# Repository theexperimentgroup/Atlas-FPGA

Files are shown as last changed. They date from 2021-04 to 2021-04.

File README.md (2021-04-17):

# PROYECTO ATLAS

La placa ATLAS se diseña con el objetivo de crear un multicore basado en SBC (SINGLE BOARD COMPUTER).

Inicialmente la placa adaptadora ATLAS es un proyecto para la placa CYC1000 y la SBC Raspberry Pi.

Mas info y fotos en este [hilo](http://www.forofpga.es/viewtopic.php?f=28&t=376&p=1548#p1548), en su propio [foro](http://www.forofpga.es/viewforum.php?f=240&sid=bd3e070f65599ff111ad0494e4459535) de foroFPGA, en [telegram](https://t.me/CYC1000) o [discord](https://discord.gg/YDdmtwh).

Licensed under Cern OHL
http://ohwr.org/cernohl

### Guía rápida

Si ya tienes tu CYC1000, una raspberry Pi, y la placa ATLAS (la puedes conseguir en el grupo de [telegram](https://t.me/CYC1000)), sigue esta guía rápida para empezar a trastear. 

El proyecto está empezando y se irán simplificando los pasos en el futuro de forma que para cargar los cores ya no será necesario acceder al terminal de Linux de la placa SBC.

#### Ensamblaje de las placas:

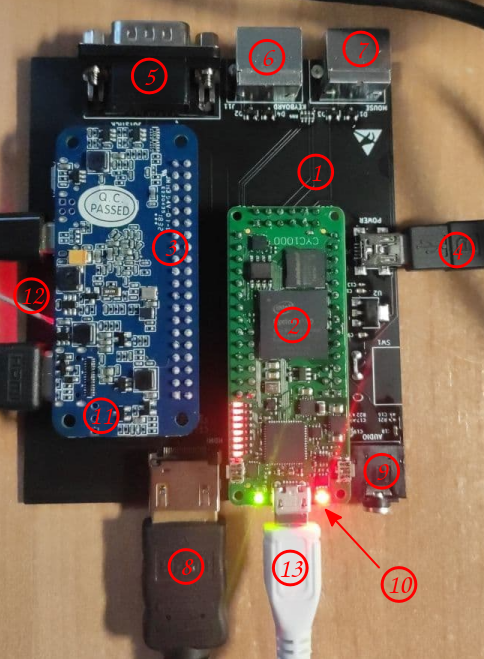
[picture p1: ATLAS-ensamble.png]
ensamblaje


Leyenda: (1) Placa Atlas, (2) FPGA CYC1000, (3) SBC Raspberry Pi, (4) Alimentación general, (5) DB9 para joystick, (6) teclado PS2, (7) ratón PS2, (8) salida video HDMI, (9) jack 3.5 audio, (10) tarjeta microSD ATLAS, (11) tarjeta microSD rPi

Otras conexiones opcionales: 

(12) Conexiones de vídeo y teclado a la SBC rPi para acceder al terminal de linux . No es necesario si has configurado acceso ssh por WiFi.

(13) USB Blaster para cargar cores directamente a la CYC1000. No es necesario si la carga se hace a través de la SBC rPi.

#### Configuración inicial de la SBC raspberry Pi

* Descarga raspberry Pi OS Lite https://www.raspberrypi.org/software/operating-systems/ y grábalo en una tarjeta micro SD
* Arranca  la SBC con la tarjeta micro SD del paso anterior en el zócalo (11) (no es necesario tenerla conectada aún a la placa ATLAS) con el video y teclado conectados y con un cargador de adecuado amperaje (>2A). 
  * Para acceder al terminal Linux de la rPI el usuario / contraseña por defecto son: pi / raspberry
* Configuración de la raspberry Pi con el comando `sudo raspi-config` (la configuración del WiFi es opcional y puedes encontrar mas información [aquí](https://www.raspberrypi.org/documentation/configuration/wireless/wireless-cli.md)): 
  * 5 Localization Options
    * L4 WLAN country 
    * L3 keyboard
  * 1 system options
    * S1 wireless LAN

#### Instalación del cargador de cores programRBF en la FPGA 

Nota: vamos a trabajar desde el directorio /home/pi que es el que aparece por defecto al arrancar el terminal Linux con el usuario "pi".

* Instala la librería WiringPi:

  ```
  wget https://project-downloads.drogon.net/wiringpi-latest.deb
  sudo dpkg -i wiringpi-latest.deb
  ```

* Compila el ejecutable para cargar los cores:

  ```
  wget https://raw.githubusercontent.com/shaeon/programrbf/main/programrbf_v01.cpp
  g++ programrbf_v01.cpp -lwiringPi -o programrbf
  ```

#### Arranca los cores desde el terminal Linux de la SBC

* Copia los cores con extensión .rbf a la tarjeta SD, en la partición "rootfs", directorio ""/home/pi".

* Carga el core con el ejecutable programrbf (el ejemplo carga el [msx_multicore2.rbf](./cores/msx_multicore2.rbf) de MSX1):

  ```
  ./programrbf msx_multicore2.rbf 17 22 4 27
  ```
  
  Nota: El core [msx_multicore2.rbf](./cores/msx_multicore2.rbf) de MSX1 requiere soldar un reloj adicional de 50 MHz, y tener una tarjeta micro SD con [este contenido](https://mega.nz/file/20pi1aiY#FwhOZryEUyuyU1gEUCVma1ndn-2BqtvH7RUx-qwgqs0) insertada en el zócalo micro SD (10) de la placa ATLAS.

#### Script para cargar un core automáticamente al arrancar la SBC

* Ejecuta los siguientes comandos en el terminal de Línux:

  ```sh
  crontab -e
  #selecciona por ejemplo nano y al final del fichero cron añade lo siguiente:
  @reboot ~/programrbf msx_multicore2.rbf 17 22 4 27
  ```

### **Reloj adicional de 50 Mhz:**

La placa CYC1000 dispone de un reloj de 12 Mhz. Algunos cores necesitan de un reloj adicional de 50 MHz a soldar en el espacio que se ve en la siguiente [foto](http://www.forofpga.es/viewtopic.php?f=240&t=390).

Dónde conseguir el reloj:

* [Arrow](https://www.arrow.com/en/products/ecs-2520mv-500-bn-tr/ecs-international?q=ECS-2520MV-500-BN-TR)

Listado de cores que van a 50 MHz:

* MSX1

### **Colaboraciones:**

Se necesita la [colaboración](https://github.com/SoCFPGA-learning/General/tree/main/Github_ayuda) para poder incrementar los recursos disponibles para la comunidad entorno esta placa de desarrollo.    

### Comunidad:

* [Telegram group](https://t.me/CYC1000) 
* [Discord channel](https://discord.gg/YDdmtwh)

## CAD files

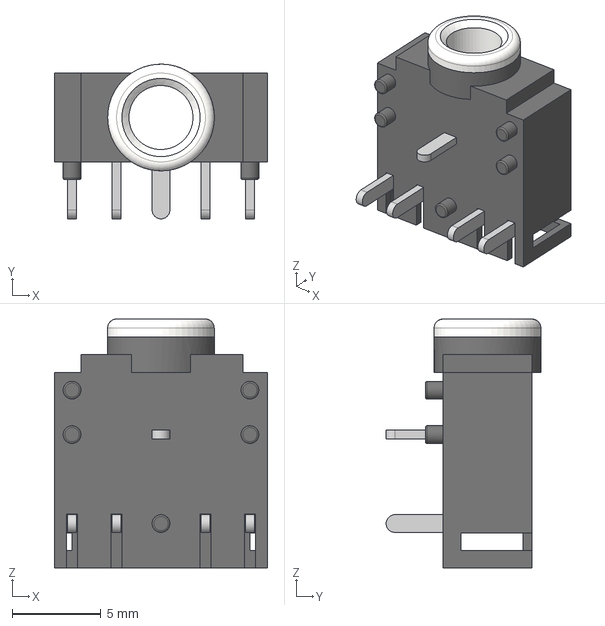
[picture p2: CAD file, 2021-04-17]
Kicad project/CYC10 Board - DIY/3D/pj-307.step
12.0 x 8.70 x 14.0 mm

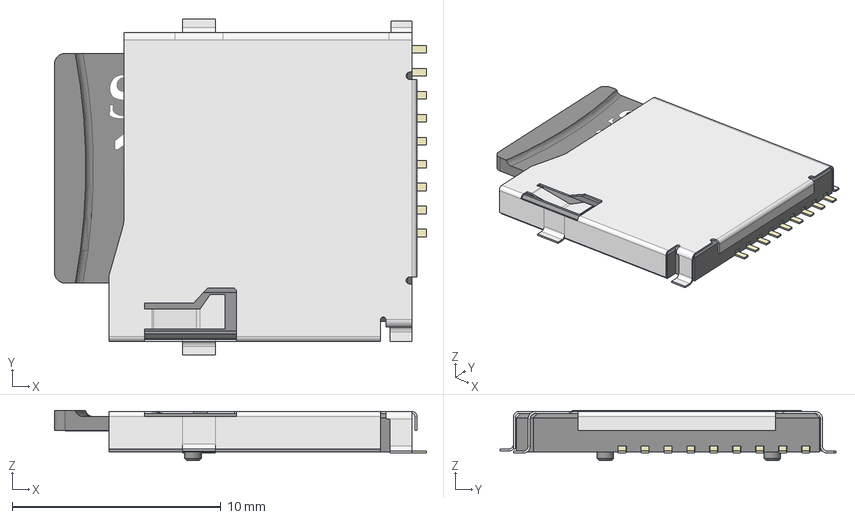
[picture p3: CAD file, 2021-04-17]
Kicad project/CYC10 Board - DIY/3D/TF-01A.step
17.8 x 16.1 x 2.40 mm

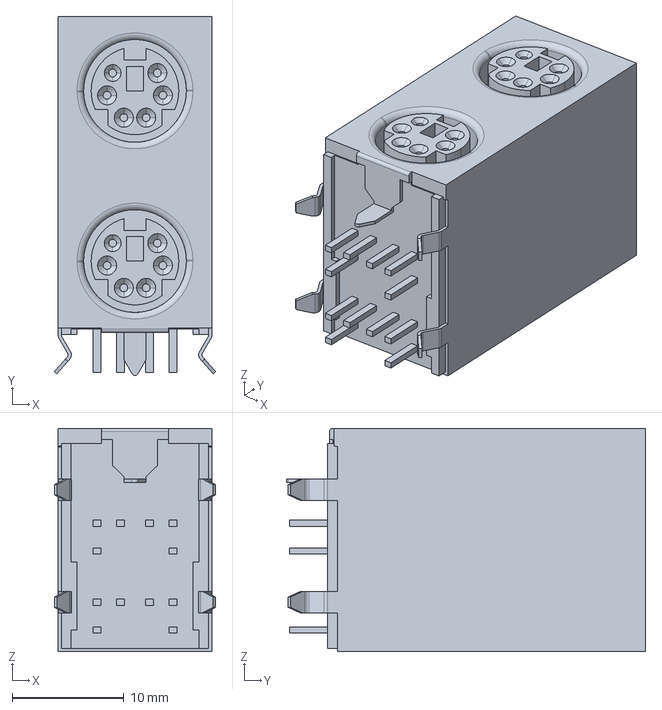
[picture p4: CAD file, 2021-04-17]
Kicad project/CYC10 Board - DIY/3D/1734021-4.stp
14.4 x 32.1 x 20.0 mm

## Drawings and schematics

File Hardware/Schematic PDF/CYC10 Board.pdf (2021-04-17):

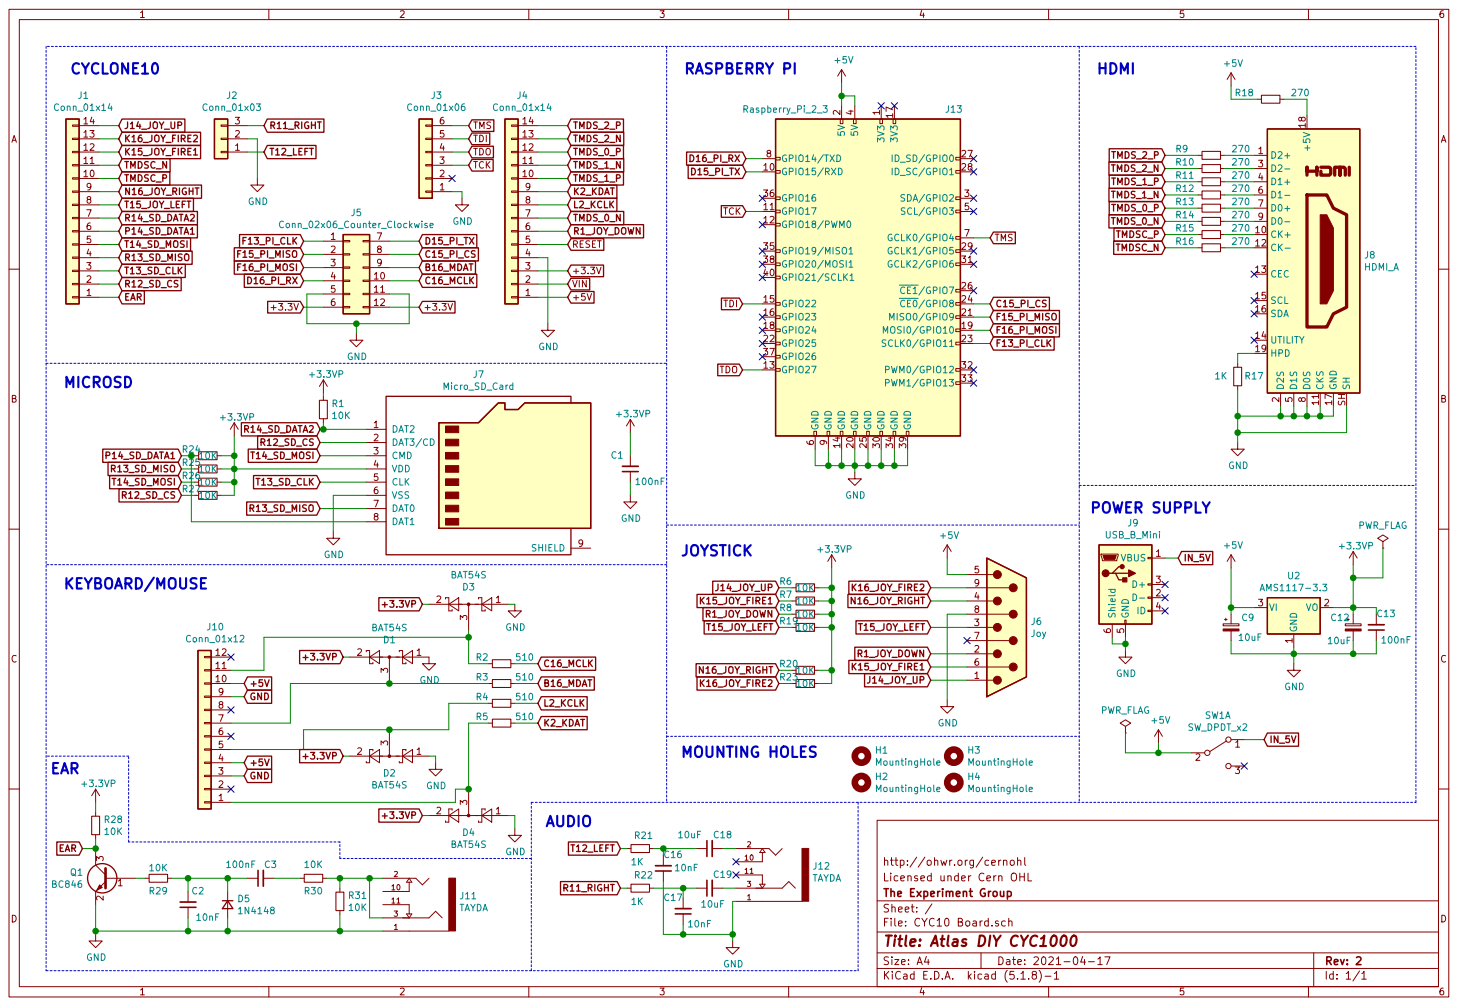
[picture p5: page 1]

CYCLONE10 | J1 Conn_01x14

Licensed under Cern OHL
File: CYC10 Board.sch Sheet: / The Experiment Group

Id: 1/1 Title: Atlas DIY CYC1000

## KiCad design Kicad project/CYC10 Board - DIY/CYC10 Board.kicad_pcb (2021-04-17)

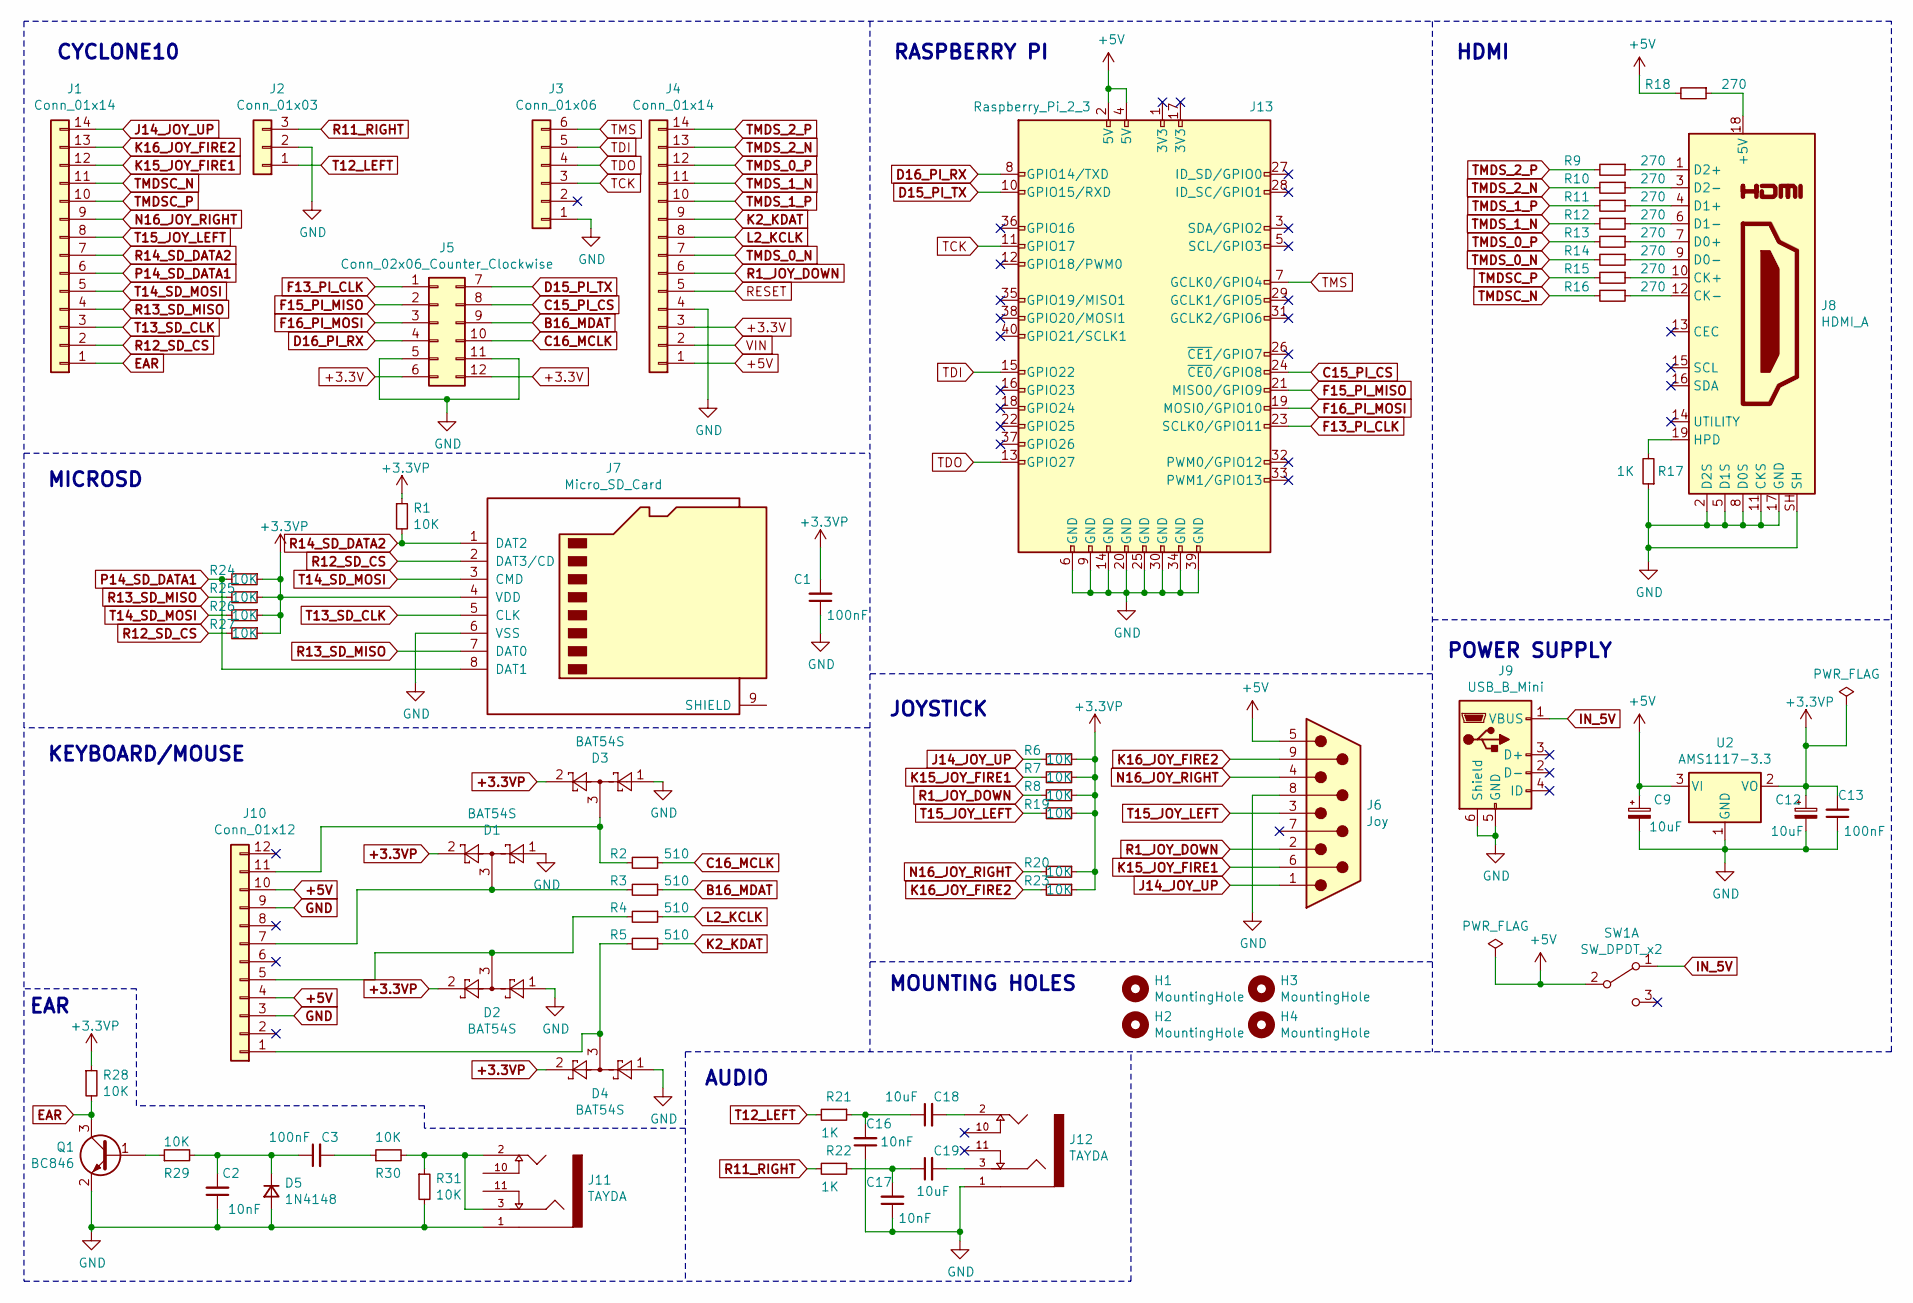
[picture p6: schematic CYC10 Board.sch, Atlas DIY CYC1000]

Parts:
C1, C3, C13: 100nF; C_0805_2012Metric
C2, C16, C17: 10nF; C_0805_2012Metric
C9, C12, C18, C19: 10uF; C_0805_2012Metric
D1, D2, D3, D4: BAT54S; SOT-23
D5: 1N4148; D_MiniMELF
H1, H2, H3, H4: MountingHole; MountingHole_3.2mm_M3
J1, J4: Conn_01x14; PinHeader_1x14_P2.54mm_Vertical
J2: Conn_01x03; PinHeader_1x03_P2.54mm_Vertical
J3: Conn_01x06; PinHeader_1x06_P2.54mm_Vertical
J5: Conn_02x06_Counter_Clockwise; PMOD
J6: Joy; DSUB-9_Male_Horizontal_P2.77x2.84mm_EdgePinOffset9.90mm_Hou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
J7: Micro_SD_Card; Conn_uSDcard1
J8: HDMI_A; HDMI_BIEN
J9: USB_B_Mini; USB_Mini-B_Wuerth_65100516121_Horizontal
J10: Conn_01x12; PS2_DOBLE
J11, J12: TAYDA; Tayda_Audio_Bien
J13: Raspberry_Pi_2_3; Conector_PI
Q1: BC846; SOT-23
R1, R6, R7, R8, R19, R20, R23, R24, R25, R26, R27, R28, R29, R30, R31: 10K; R_0805_2012Metric
R2, R3, R4, R5: 510; R_0805_2012Metric
R9, R10, R11, R12, R13, R14, R15, R16, R18: 270; R_0805_2012Metric
R17, R21, R22: 1K; R_0805_2012Metric
SW1: SW_DPDT_x2; Switch
U2: AMS1117-3.3; SOT-223-3_TabPin2

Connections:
+3.3V: J4.3, J5.6, J5.12
+3.3VP: C1.2, C12.1, C13.2, D1.2, D2.2, D3.2, D4.2, J7.4 (VDD), R1.1, R6.1, R7.1, R8.1, R19.1, R20.1, R23.1, R24.1, R25.1, R26.1, R27.1, R28.1, U2.2 (VO)
+5V: C9.1, J4.1, J6.5, J10.4, J10.10, J13.2 (5V), J13.4 (5V), R18.2, SW1.2 (B), U2.3 (VI)
B16_MDAT: J5.9, R3.1
C15_PI_CS: J5.8, J13.24 (~CE0~/GPIO8)
C16_MCLK: J5.10, R2.1
D15_PI_TX: J5.7, J13.10 (GPIO15/RXD)
D16_PI_RX: J5.4, J13.8 (GPIO14/TXD)
EAR: J1.1, Q1.3 (C), R28.2
F13_PI_CLK: J5.1, J13.23 (SCLK0/GPIO11)
F15_PI_MISO: J5.2, J13.21 (MISO0/GPIO9)
F16_PI_MOSI: J5.3, J13.19 (MOSI0/GPIO10)
GND: C1.1, C2.1, C9.2, C12.2, C13.1, C16.1, C17.1, D1.1, D2.1, D3.1, D4.1, D5.2 (A), J2.2, J3.1, J4.4, J5.5, J5.11, J6.8, J7.6 (VSS), J8.2 (D2S), J8.5 (D1S), J8.8 (D0S), J8.11 (CKS), J8.17 (GND), J8.SH, J9.5 (GND), J9.6 (Shield), J10.3, J10.9, J11.1, J12.1, J13.6 (GND), J13.9 (GND), J13.14 (GND), J13.20 (GND), J13.25 (GND), J13.30 (GND), J13.34 (GND), J13.39 (GND), Q1.2 (E), R17.1, R31.2, U2.1 (GND)
IN_5V: J9.1 (VBUS), SW1.1 (A)
J14_JOY_UP: J1.14, J6.1, R6.2
K2_KDAT: J4.9, R5.1
K15_JOY_FIRE1: J1.12, J6.6, R7.2
K16_JOY_FIRE2: J1.13, J6.9, R23.2
L2_KCLK: J4.8, R4.1
N16_JOY_RIGHT: J1.9, J6.4, R20.2
unnamed: C2.2, C3.1, D5.1 (K), R29.2
unnamed: C3.2, R30.1
unnamed: C16.2, C18.1, R21.1
unnamed: C17.2, C19.1, R22.1
unnamed: C18.2, J12.2
unnamed: C19.2, J12.3
unnamed: D1.3, J10.7, R3.2
unnamed: D2.3, J10.5, R4.2
unnamed: D3.3, J10.11, R2.2
unnamed: D4.3, J10.1, R5.2
unnamed: J8.1 (D2+), R9.1
unnamed: J8.3 (D2-), R10.1
unnamed: J8.4 (D1+), R11.1
unnamed: J8.6 (D1-), R12.1
unnamed: J8.7 (D0+), R13.1
unnamed: J8.9 (D0-), R14.1
unnamed: J8.10 (CK+), R15.1
unnamed: J8.12 (CK-), R16.1
unnamed: J8.18 (+5V), R18.1
unnamed: J8.19 (HPD), R17.2
unnamed: J11.2, J11.3, R30.2, R31.1
unnamed: Q1.1 (B), R29.1
P14_SD_DATA1: J1.6, J7.8 (DAT1), R24.2
R1_JOY_DOWN: J4.6, J6.2, R8.2
R11_RIGHT: J2.3, R22.2
R12_SD_CS: J1.2, J7.2 (DAT3/CD), R27.2
R13_SD_MISO: J1.4, J7.7 (DAT0), R25.2
R14_SD_DATA2: J1.7, J7.1 (DAT2), R1.2
RESET: J4.5
T12_LEFT: J2.1, R21.2
T13_SD_CLK: J1.3, J7.5 (CLK)
T14_SD_MOSI: J1.5, J7.3 (CMD), R26.2
T15_JOY_LEFT: J1.8, J6.3, R19.2
TCK: J3.3, J13.11 (GPIO17)
TDI: J3.5, J13.15 (GPIO22)
TDO: J3.4, J13.13 (GPIO27)
TMDSC_N: J1.11, R16.2
TMDSC_P: J1.10, R15.2
TMDS_0_N: J4.7, R14.2
TMDS_0_P: J4.12, R13.2
TMDS_1_N: J4.11, R12.2
TMDS_1_P: J4.10, R11.2
TMDS_2_N: J4.13, R10.2
TMDS_2_P: J4.14, R9.2
TMS: J3.6, J13.7 (GCLK0/GPIO4)
VIN: J4.2

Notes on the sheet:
JOYSTICK
POWER SUPPLY
AUDIO
KEYBOARD/MOUSE
MICROSD
CYCLONE10
RASPBERRY PI
HDMI
MOUNTING HOLES
EAR

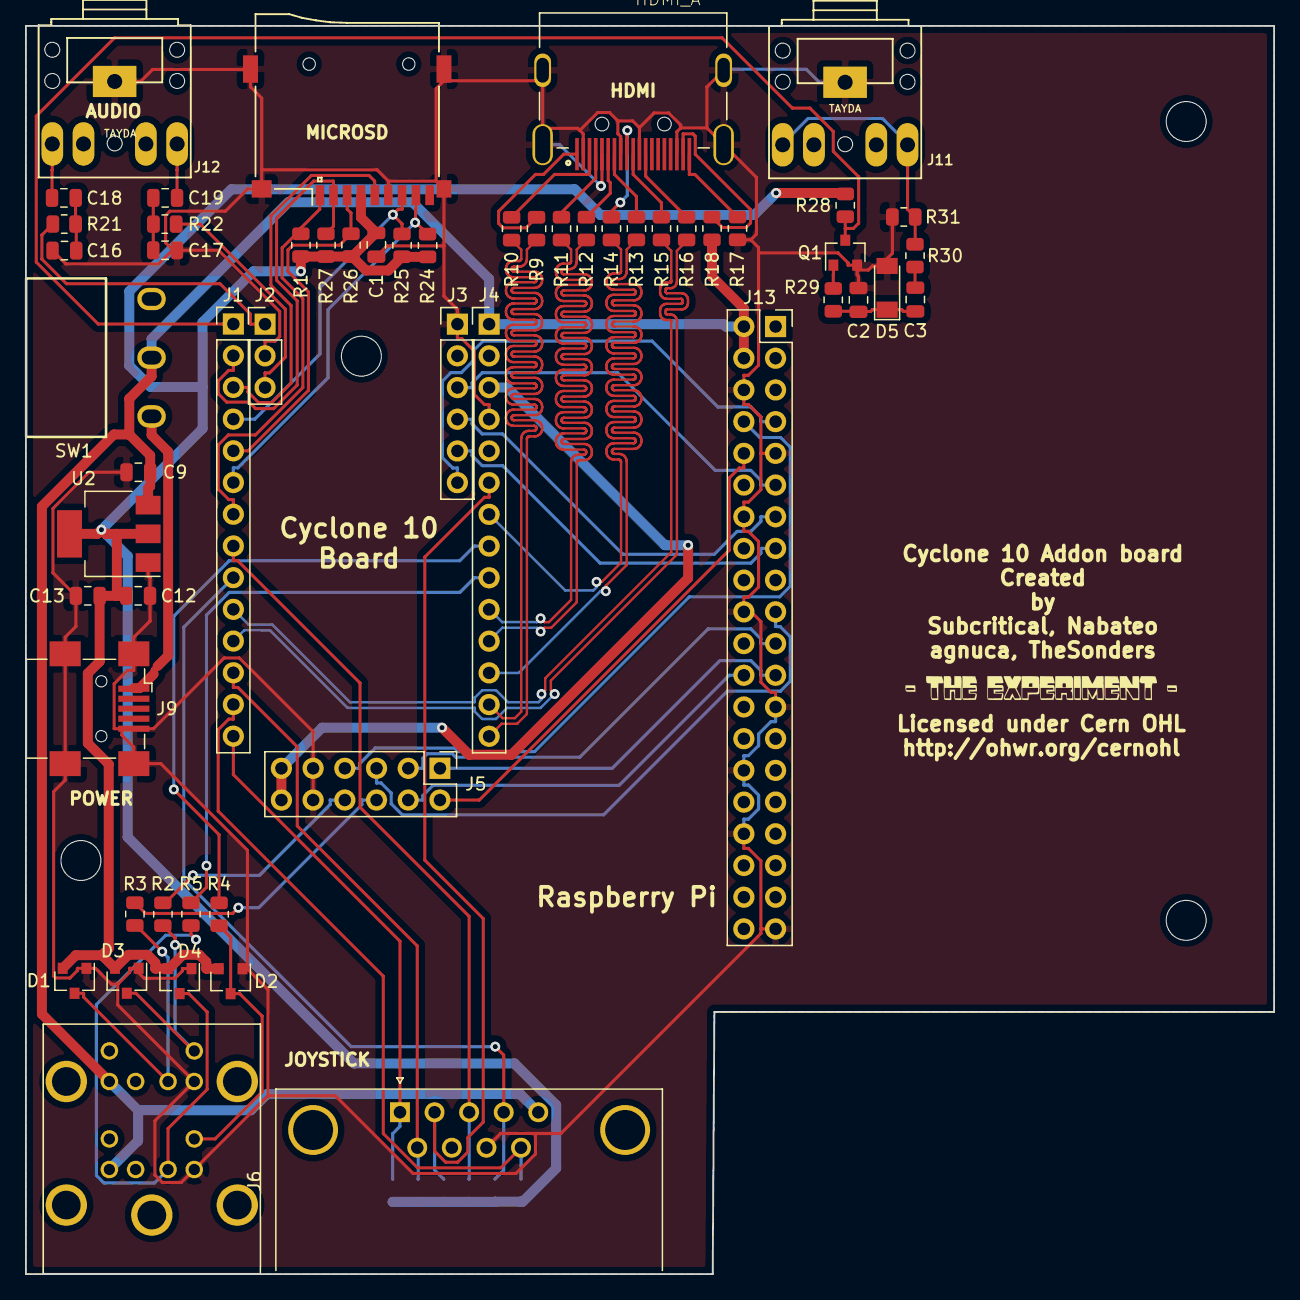
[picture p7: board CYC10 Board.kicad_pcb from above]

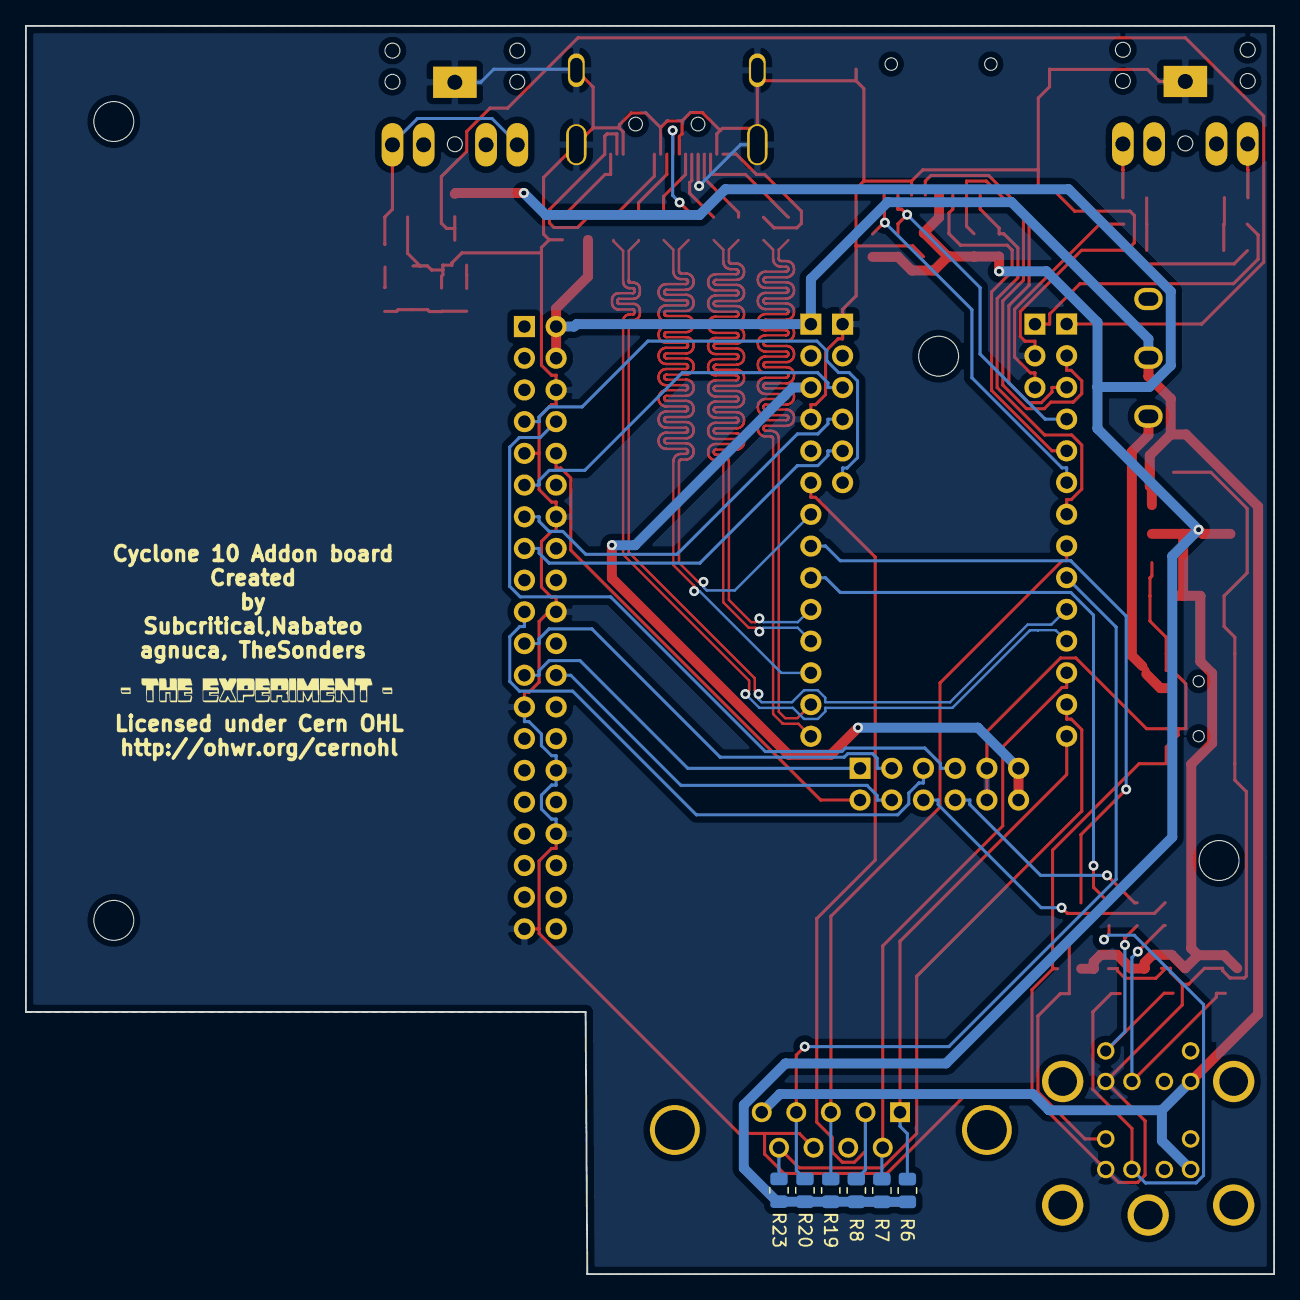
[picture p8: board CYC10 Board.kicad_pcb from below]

Board: 2 copper layers, 100.0 x 100.0 mm, 66 parts (6 on the bottom side), 64 nets.
